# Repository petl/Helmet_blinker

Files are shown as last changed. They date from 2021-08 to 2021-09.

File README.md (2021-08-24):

<p><h2> Motivation</h2> </p><br />
Last year I got a new helmet to make cycling for myself a bit safer. The helmet is an ABUS Hyban 2.0 in a stylish color with an integrated LED backlight, which helps others see me at night. Unfortunately the original light is powered by a single CR2032 coin cell, which not only limits its runtime severely, but also is not rechargeable. There even is a <a href='https://www.youtube.com/watch?v=HbjWTI32BtE'>video</a> on how to change the coin cell. This itself is just how ABUS makes products, but what really dumbfounded me were the misaligned LEDs. They just light straight into the rubber part of the light and only some scattered light can be seen from outside. Interestingly enough, the light made it to version 6 as the photo below shows "ACHV_V06". <br><br>
Long story short: I made a rechargeable drop in replacement for the original light. <br><br>

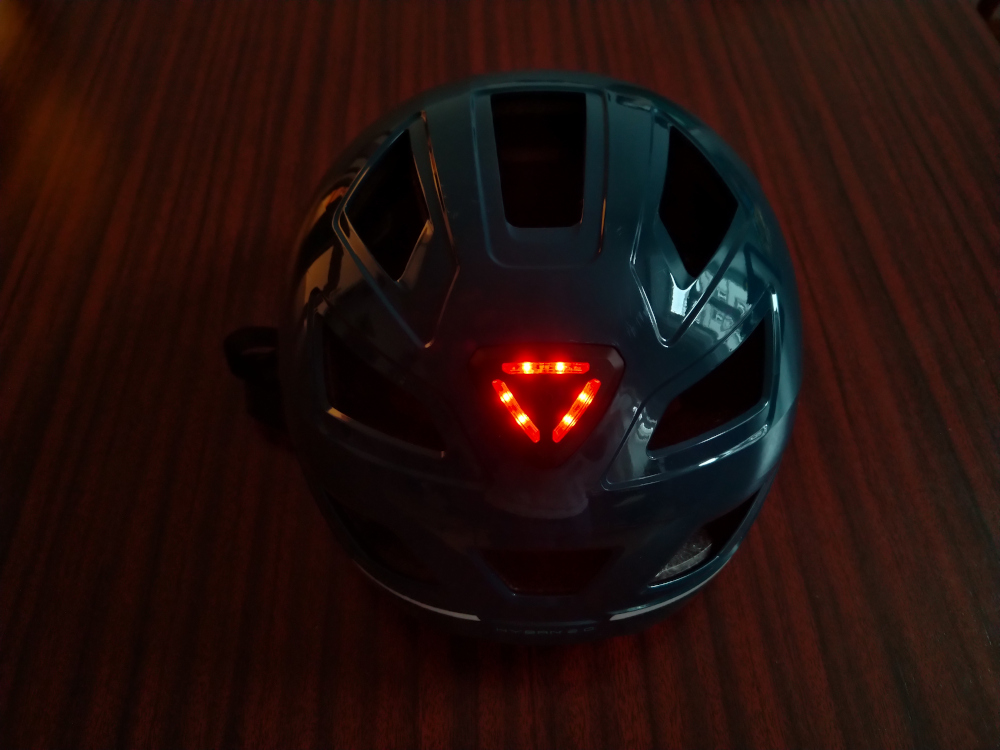
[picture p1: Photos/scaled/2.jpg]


<p>If you're interested in this project, take a look at the <a href='https://quiescentcurrent.com/blog/post.php?p_id=67'>blog</a> or just write a message or leave a comment. If you want to buy one, here's the tindie link: <a href='https://www.tindie.com/products/petl/rechargeable-led-bicycle-helmet-light/'>Rechargeable LED bicycle helmet light</a>   </p>

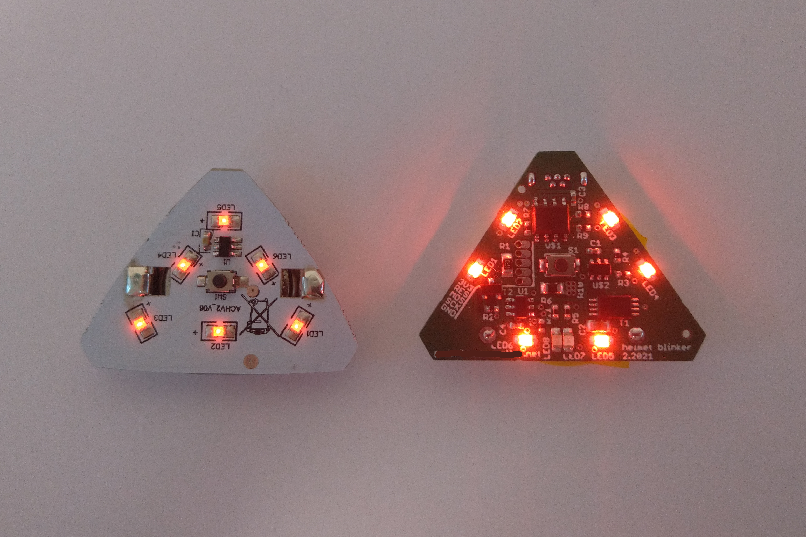
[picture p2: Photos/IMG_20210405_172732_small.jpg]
<p align="right">
<br>The original light on the left, the new one on the right.</p>  <p>

<h2> Schematics </h2> </p>
There probably is a reason why the original light was not rechargeable and it's most certainly money. The most complex part for the PCB was the charging solution around the TP4056 IC. The LiPo is fully protected: over- and undervoltage, temperature limit and short circuit. There is not a lot that can go wrong anymore with the battery which is a reassuring since it is worn near your head. <br><br>
Besides this, the most interesting area is around the ATTiny10 microcontroller. It get programmed via a programming header which I made myself out of some pogo pins. It can detect the push button being pressed and then run some funky blinking on the six red LEDs. <br><br>
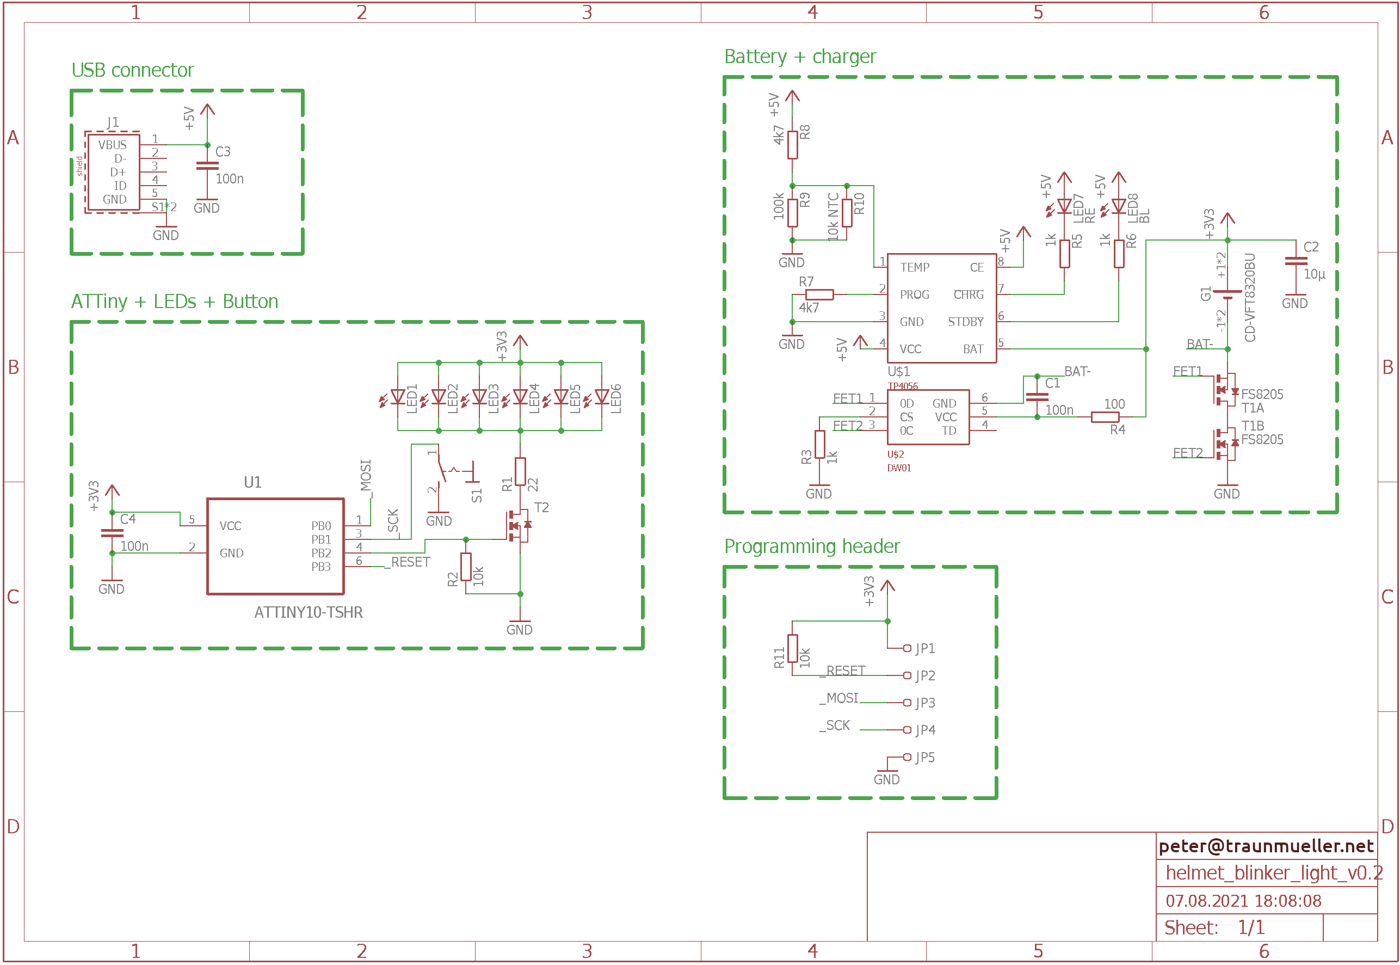
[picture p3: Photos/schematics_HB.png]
<p align="right">
<br>Schematics for v0.2.</p> 

<h2> Hardware </h2> </p>
<p>The hardware assembly was mostly done by jlcpcb (unfortunately not a sponsor). I only had to do the battery and USB connector. The connector itself is a 90° micro USB which snugs in perfectly next to the battery and rubber protector. A great amount of measuring wnet into the correct positioning of the 6 red LEDs bedind the plastic reflector. This worked out surplrisingly well as the can be individually seen in the top photo. </p>

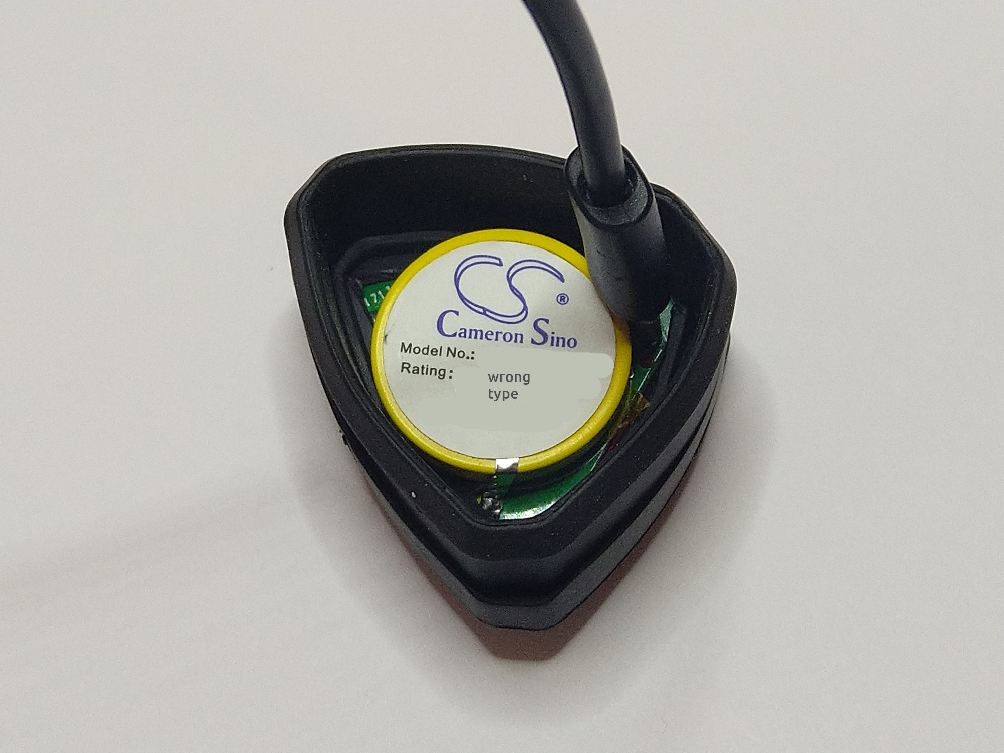
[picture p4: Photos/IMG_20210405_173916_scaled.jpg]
<p align="right">
<br>Backside of the light while charging</p> 

Since there are always at least 5 PCBs assembled, I got to take a nice shot of them. If you want one for yourself, just shoot me a mail, they are v0.1 though. <br><br>
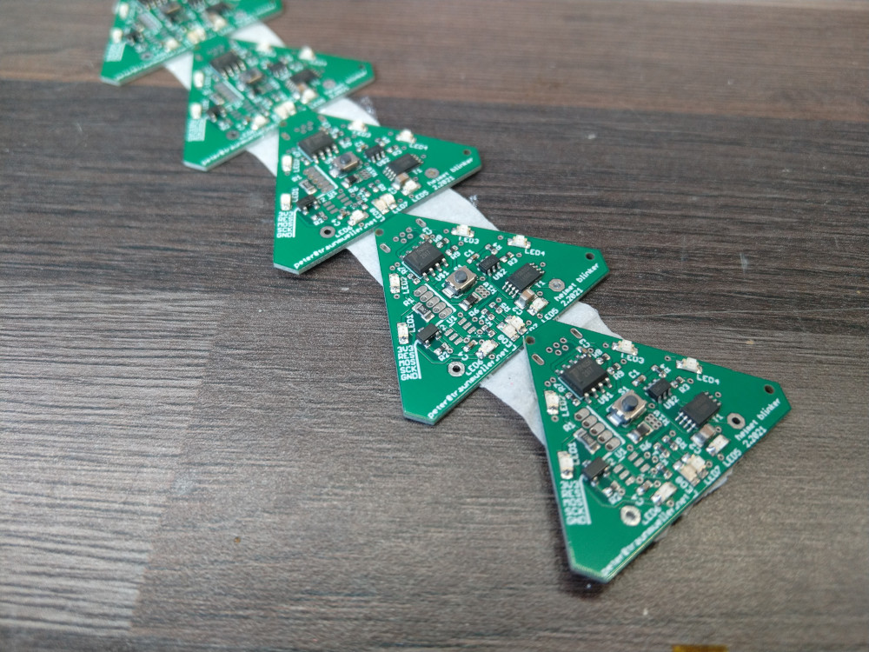
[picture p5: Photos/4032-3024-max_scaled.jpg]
<p align="right">
<br>PCBs to make more lights. </p> 

There are two more LEDs on the PCB, they are charging indicators and are directly switched by the TP4056.

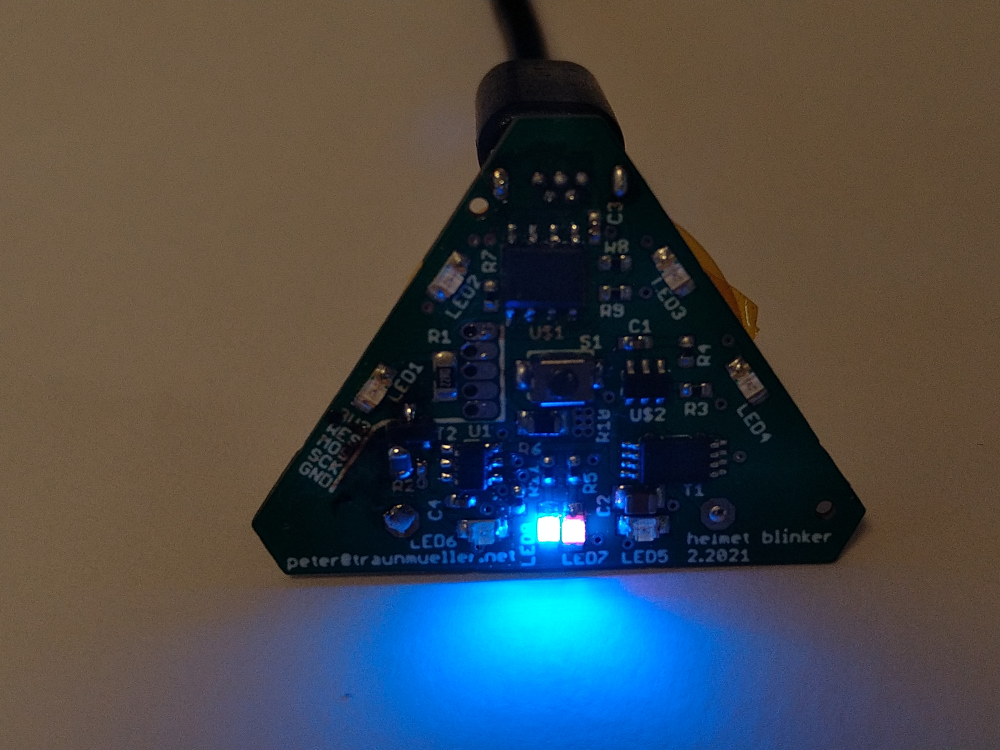
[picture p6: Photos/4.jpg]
<p align="right">
<br>Charging indicators for the LiPo cell.</p> 

<h2> Software </h2> </p>
<p>Programming an ATTiny10 was more challenging than expected. Although it is an Atmel microcontroller out of the AT* family it behaves quite differently than the ATTiny 84 or 85 for example. It does not feature a real ICSP programming input and can therefore not just be programmed with the Arduino IDE and a library. The programming protocol is called TPI (Tiny Programming Interface) and luckily  <a href='http://www.technoblogy.com/show?1YQY '>technoblogy</a>  already worked that one out, big thanks to them! It only took me almost a week to find their solution and order the recommended "USBasp" programmer, so use this information wisely. After that is is quite straight forward, a lot of low level register magic combined with the incredibly low power deep sleep of the tiny. There are 4 different modes which are cycled through by pressing the button:<br>
 <ul>
  <li>1: 100% on</li>
  <li>2: 50% on, 500ms period</li>
  <li>3: 20% on, 300ms period</li>
  <li>4: 3% on, 1000ms period</li>
</ul> <br>
 </p>
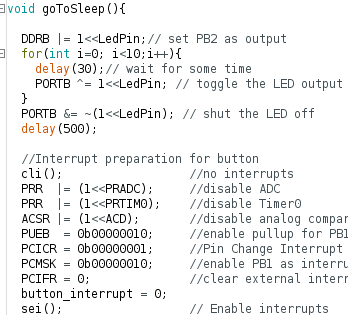
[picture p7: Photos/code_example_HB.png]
<p align="right">
<br>Screenshow of the code: <a href='https://github.com/petl/Helmet_blinker'>source</a>  .</p> 

<h2> Runtime </h2> </p>
<p>The most important question was the possible runtime of the setup. The <a href='https://www.ebay.at/itm/332602314162'>battery</a> used is a 3.6V 120mAh LiPo which drives the 6 LEDs at ~10mA each, the ATTiny draws 0.2mA while running. This means that in mode 1 it can do roughly 2h on a single charge. In mode 4, this runtime goes up to 65h, since it is only pulsing the LEDs. <br><br>
Standby time can be calculated with the deep sleep current of the ATTiny of <0.1µA. This would result in 1.5 million hours standy time.. More realistically the rest of the circuit uses more current and limits this time. It still is an impressive number and will definitely be the clickbait in case I make a video about this.  
</p>

<h2> Conclusion </h2> </p>
So that's that, I hope this guide didn't get too long. All the files are on the <a href='https://quiescentcurrent.com/blog/post.php?p_id=67'>blog</a> so you can download them and browse through. I did contact ABUS Germany about my design and the idea to make their products rechargeable, but they never answered. If you have any questions or feedback just write a message or leave a comment <3            <br /><br />

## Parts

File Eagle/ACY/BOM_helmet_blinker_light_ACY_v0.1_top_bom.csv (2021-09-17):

Comment | Designator | Footprint | LCSC Part #
100n | C1 C3 C4 | C0402K | C1525
10µ | C2 | C0805K | C15850
LED RED | LED1 LED2 LED3 LED4 LED5 LED6 | CHIPLED_0805 | C84256
LED RED | LED7 | CHIPLED_0603 | C2286
LED BLUE | LED8 | CHIPLED_0603 | C72041
22 | R1 | R0805 | C17561
10k NTC | R10 | R0805 | C51597
10k | R2 R11 | R0402 | C25744
1k | R3 R5 R6 | R0402 | C11702
100 | R4 | R0402 | C25076
4k7 | R7 R8 | R0402 | C25900
100k | R9 | R0402 | C25741
Switch | S1 | TS-1088 | C720477
FS8205A | T1 | TSSOP-8 | C16052
N-FET | T2 | SOT-23 | C20917
TP4056 | U$1 | ESOP23-8 | C16581
DW01 | U$2 | SOT23-6 | C14213
ATTINY10-TSHR | U1 | SOT95P280X145-6N | C128438

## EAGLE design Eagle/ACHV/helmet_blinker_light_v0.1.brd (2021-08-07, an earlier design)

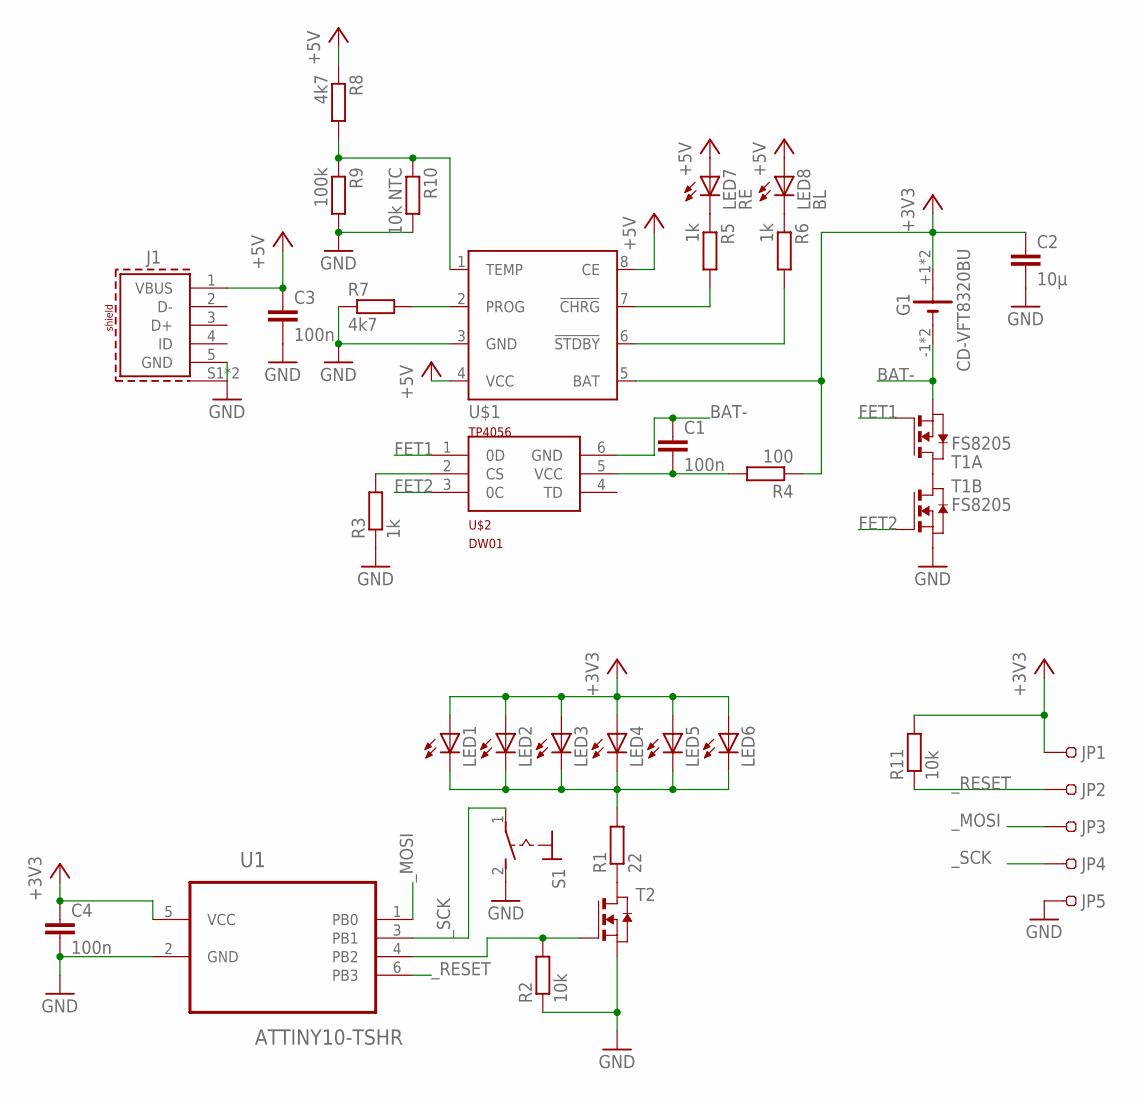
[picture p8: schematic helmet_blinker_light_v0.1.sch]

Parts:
C1, C3, C4: 100n; C0402K
C2: 10µ; C0805K
G1: CD-VFT8320BU; CS-VFT8320BU
J1: 614105150621
JP1, JP2, JP3, JP4, JP5: 0.7MM_POGO-PINS
LED1, LED2, LED3, LED4, LED5, LED6: LEDCHIPLED_0805; CHIPLED_0805
LED7: RE; CHIPLED_0805
LED8: BL; CHIPLED_0805
R1: 22; R0805
R2, R11: 10k; R0402
R3, R5, R6: 1k; R0402
R4: 100; R0402
R7, R8: 4k7; R0402
R9: 100k; R0402
R10: 10k NTC; R0805
S1: TS-1088
T1: FS8205; TSSOP-8
T2: NMOSSOT23; SOT-23
U1: ATTINY10-TSHR; SOT95P280X145-6N
U$1: TP4056; SOT23-8
U$2: DW01; SOT23-6

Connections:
+3V3: C2.1, C4.1, G1.+1 (+), G1.+2 (+), JP1.1, LED1.A, LED2.A, LED3.A, LED4.A, LED5.A, LED6.A, R4.1, R11.2, U1.5 (VCC), U$1.5 (BAT)
+5V: C3.1, J1.1 (VBUS), LED7.A, LED8.A, R8.1, U$1.4 (VCC), U$1.8 (CE)
BAT-: C1.1, G1.-1 (-), G1.-2 (-), T1.2 (S), T1.3 (S), U$2.6 (GND)
FET1: T1.4 (G), U$2.1 (0D)
FET2: T1.5 (G), U$2.3 (0C)
GND: C2.2, C3.2, C4.2, J1.5 (GND), J1.S1 (SHIELD), J1.S2 (SHIELD), JP5.1, R2.1, R3.1, R7.1, R9.2, R10.2, S1.2 (S), T1.6 (S), T1.7 (S), T2.2 (S), U1.2 (GND), U$1.3 (GND)
unnamed: T1.1 (D), T1.8 (D)
unnamed: R1.1, T2.1 (D)
unnamed: R3.2, U$2.2 (CS)
unnamed: R2.2, T2.3 (G), U1.4 (PB2)
unnamed: LED1.C, LED2.C, LED3.C, LED4.C, LED5.C, LED6.C, R1.2
unnamed: C1.2, R4.2, U$2.5 (VCC)
unnamed: R7.2, U$1.2 (PROG)
unnamed: R6.2, U$1.6 (!STDBY)
unnamed: LED7.C, R5.1
unnamed: LED8.C, R6.1
unnamed: R5.2, U$1.7 (!CHRG)
unnamed: R8.2, R9.1, R10.1, U$1.1 (TEMP)
_MOSI: JP3.1, U1.1 (PB0)
_RESET: JP2.1, R11.1, U1.6 (PB3)
_SCK: JP4.1, S1.1, U1.3 (PB1)

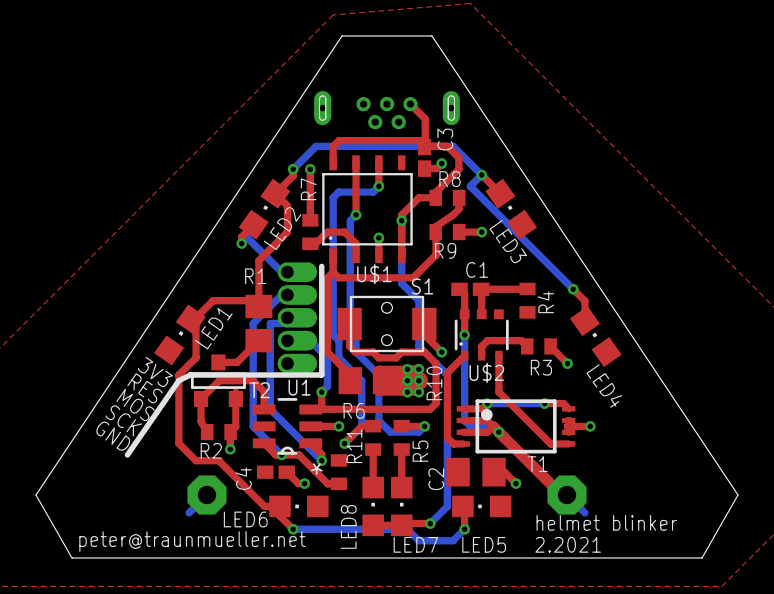
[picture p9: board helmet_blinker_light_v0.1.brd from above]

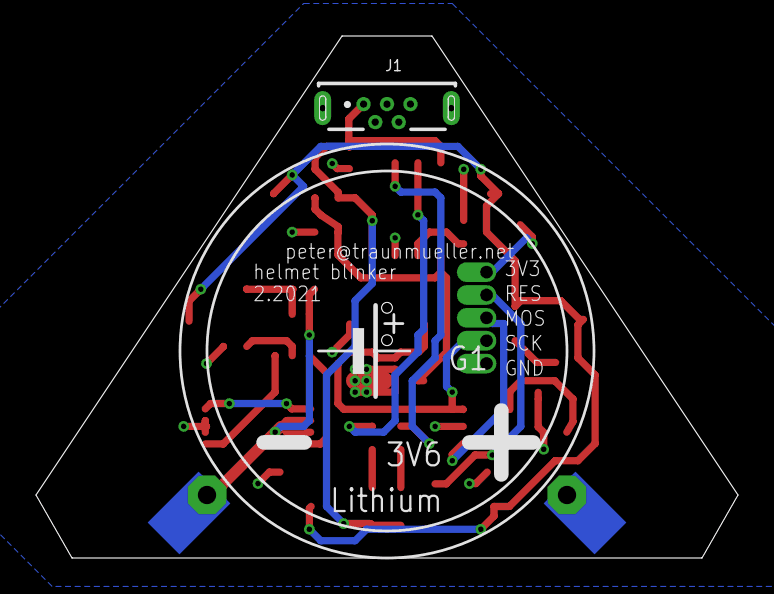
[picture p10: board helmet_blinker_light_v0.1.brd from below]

Board: 2 copper layers, 39.0 x 29.0 mm, 36 parts (2 on the bottom side), 21 nets.

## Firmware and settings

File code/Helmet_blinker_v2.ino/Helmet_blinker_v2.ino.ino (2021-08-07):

#include <avr/sleep.h>
#include <avr/interrupt.h>


const int LedPin = 2;
volatile int button_interrupt = 0;


// the setup function runs once when you press reset or power the board
void setup() {

  // Configure pins
  //DDRB |= 1<<LedPin;// set PB2 as output
  //PORTB = 0;      // All low


  //goToSleep();
  
  //CCP = 0xD8;                       // Allow change of protected register
  //CLKPSR = 0;                       // Switch to 8MHz clock

}

// the loop function runs over and over again forever
void loop() {
  button_interrupt = 2;
  defaultProgram();   
  goToSleep();//go to sleep  
}

ISR(PCINT0_vect) {// This is called when the interrupt occurs, 
  PCICR = 0x00;    // Pin Change Interrupt Control Register set to DISABLE PCINT Interrupt 

  if(button_interrupt == 0){
    button_interrupt = 1; //the interrupt has happened
    
    DDRB |= 1<<LedPin;// set PB2 as output
    
    while( bit_is_clear(PINB, PINB1) ){//while button is pressed
      PORTB ^= 1<<LedPin; // toggle the LED output to make it blink
      delay(200);
    }  
  }
}
  
void delay (int millis) {
  for (volatile unsigned int i = 34*millis; i>0; i--);
}

void defaultProgram(){
  DDRB |= 1<<LedPin;// set PB2 as output

  //interrupt has happened, do something
  PORTB |= 1<<LedPin;//LED high
  delay(500);  
  
  while(button_interrupt == 2){//LED is on, watch for next press
    PORTB ^= 1<<LedPin; // toggle the LED output to make it blink
    if( bit_is_clear(PINB, PINB1) ){//if button is pressed
      PORTB &= ~(1<<LedPin); // shut the LED off
      button_interrupt = 3;
      delay(200);    
    }
    delay(40);   
  }
    
  while(button_interrupt == 3){//LED is in blinky mode
    PORTB ^= 1<<LedPin; // toggle the LED output to make it blink
    for(int i=0; i<50;i++){
      delay(10);// wait for some time
      if( bit_is_clear(PINB, PINB1) ){//if button is pressed
        PORTB &= ~(1<<LedPin); // shut the LED off
        button_interrupt = 4;
        delay(200);  
      }                  
    }
  }
        
 
  while(button_interrupt == 4){//LED is in fast blinky mode
    PORTB |= 1<<LedPin;//LED high
    for(int i=0; i<5;i++){
      delay(10);// wait for some time
      if( bit_is_clear(PINB, PINB1) ){//if button is pressed
        PORTB &= ~(1<<LedPin); // shut the LED off
        button_interrupt = 5;
        delay(200);   
      }                  
    }  
    PORTB &= ~(1<<LedPin); // shut the LED off
    for(int i=0; i<25;i++){
      delay(10);// wait for some time
      if( bit_is_clear(PINB, PINB1) ){//if button is pressed
        PORTB &= ~(1<<LedPin); // shut the LED off
        button_interrupt = 5;
        delay(200); 
      }                  
    }

  }
    
  while(button_interrupt == 5){//LED is in fast energysaving blinky mode
    PORTB |= 1<<LedPin;//LED high
    for(int i=0; i<3;i++){
      delay(10);// wait for some time
      if( bit_is_clear(PINB, PINB1) ){//if button is pressed
        PORTB &= ~(1<<LedPin); // shut the LED off
        button_interrupt = 6;
        //goToSleep();//go to sleep  
      }                  
    }  
    PORTB &= ~(1<<LedPin); // shut the LED off
    for(int i=0; i<100;i++){
      delay(10);// wait for some time
      if( bit_is_clear(PINB, PINB1) ){//if button is pressed
        PORTB &= ~(1<<LedPin); // shut the LED off
        button_interrupt = 6;
        //goToSleep();//go to sleep  
      }                  
    }
  }
}

void goToSleep(){
  
  DDRB |= 1<<LedPin;// set PB2 as output
  for(int i=0; i<100; i++){
    PORTB ^= 1<<LedPin; // toggle the LED output to make it blink
    delay(20);// wait for some time                 
  }
  PORTB &= ~(1<<LedPin); // shut the LED off
  DDRB &= ~(1<<LedPin); //set pin as floating




  
  //Interrupt preparation for button
  cli();                  //no interrupts
  PRR  |= (1<<PRADC);     //disable ADC
  PRR  |= (1<<PRTIM0);    //disable Timer0
  ACSR |= (1<<ACD);       //disable analog comparator
  PUEB  = 0b00000010;     //enable pullup for PB1 
  //EIMSK = 0b00000001;     //External Interrupt Request 0 Enable 
  PCICR = 0b00000001;     //Pin Change Interrupt Control Register set to enable PCINT Interrupt  
  PCMSK = 0b00000010;     //enable PB1 as interrupt source
  //EICRA = 0b00000010;     //enable INT0 falling edge interrupt  
  //EICRA = 0b00000000;     //enable INT0 low level interrupt  
  PCIFR = 0; //clear external interrupt flag register
  sei();                  // Enable interrupts
/*
          for(int i=0; i<10; i++){
      PORTB ^= 1<<LedPin; // toggle the LED output to make it blink
      delay(100);// wait for some time                 
      }*/

  button_interrupt = 0; //clear interrupt


  //PORTB &= ~(1<<LedPin); // shut the LED off
  //DDRB &= ~(1<<LedPin); //set pin as floating
  //sleep mode
  SMCR = 0b00000011;  //Sleep mode is power down AND sleep is enabled
  //set_sleep_mode(SLEEP_MODE_PWR_DOWN);  //Sleep mode is power down  
  //sleep_enable();                         // Sets the Sleep Enable bit in the MCUCR Register (SE BIT)
  sleep_cpu();                            // sleep
}

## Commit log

2021-08-07 published to github
    [Patches_helmet_blinker_v0.1.ods, helmet_blinker_light_v0.1.brd, helmet_blinker_light_v0.1.sch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]
2021-08-20 added PnP files
    [BOM_JLC_Helmet_blinker_light_v0.2.xlsx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]
2021-09-17 split ACHV and ACY models
    [BOM_JLC_Helmet_blinker_light_v0.2.xlsx, BOM_helmet_blinker_light_ACY_v0.1_top_bom.csv, Patches_helmet_blinker_v0.1.ods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]
2021-09-17 reordered files for ACY vs ACHV models
    [BOM_JLC_Helmet_blinker_light_v0.2.xlsx, Patches_helmet_blinker_v0.1.ods, helmet_blinker_light_v0.1.brd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]

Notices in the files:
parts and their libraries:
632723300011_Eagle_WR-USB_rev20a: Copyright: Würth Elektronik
